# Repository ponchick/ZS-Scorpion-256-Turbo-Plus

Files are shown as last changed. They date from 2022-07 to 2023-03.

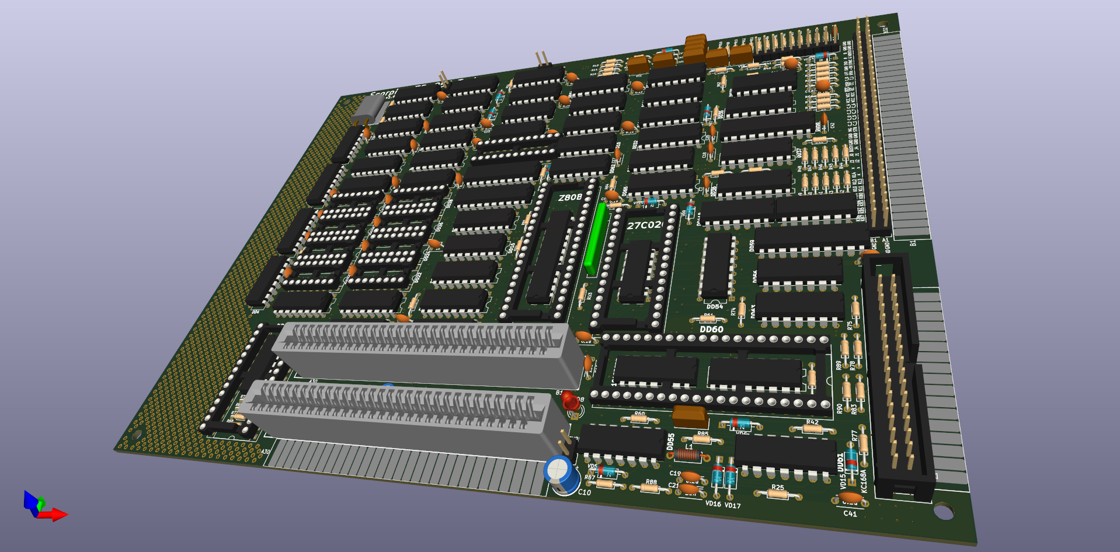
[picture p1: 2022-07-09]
Images/3D.png

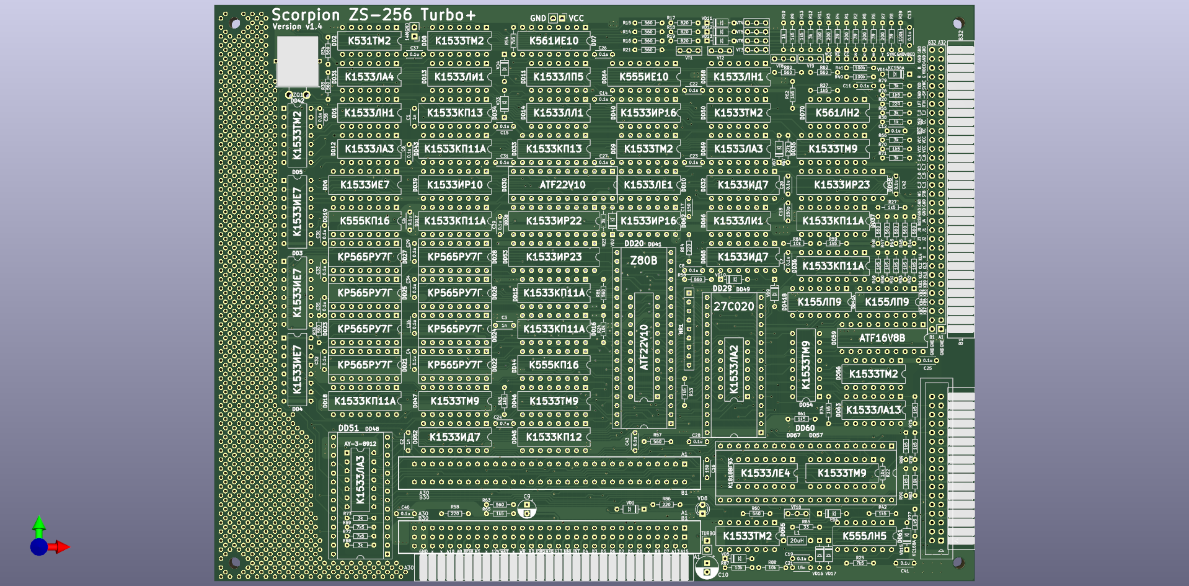
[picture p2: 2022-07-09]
Images/TOP.png

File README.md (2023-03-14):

# ZS-Scorpion-256-Turbo-Plus
Про плату хорошо написано в [этом репозитории](https://github.com/romychs/Scorpion256TPlus). Лучше я не напишу, а просто копировать не вижу смысла.

**Внимание! На данный момент произведена только первая пробная партия плат, в ней присутствуют ошибки. Если хотите отлаженую плату - заказывайте плату из репозотория выше.**
## Схема
[Схема](https://github.com/ponchick/ZS-Scorpion-256-Turbo-Plus/blob/main/gerber/Scorpion.pdf) в основном срисована со схемы @romychs версии 16.2.4. В основном отличия чисто косметические, но есть и более серьезные отличия:
- Добавлено больше деблокировочных конденсаторов.
- Возвращены краевые разъемы. В теории они должны нормально дружить как с разъемами с шагом 2,54 мм, так и с шагом 2,5 мм.
- Убрана макетка внизу платы в пользу более широких дорожек питания.
- Добавлена нормально-замкнутая перемычка на 6 ножку DD37. По умолчанию ножка притянута к земле, но можно перерезать перемычку и задействовать этот контакт для своих целей. К примеру, можно завести сигнал KEMPSTON-джойстика FIRE2.
- Добавлен необязательный планарный резистор R28. Он необходим только для [доработки выбора порта #7FFD по команде по команде "OUT(#FD),A"](https://github.com/ponchick/ZS-Scorpion-256-Turbo-Plus/blob/main/Images/7ffd.jpg)- в этом случае нужно перерезать дорожку между контактными площадками этого резистора и впаять сам резистор. Изначально доработка была сделана для ZXM-Phoenix, работает и для зелёного ZS Scorpion. Подробней можно почитать [тут](https://zx.clan.su/forum/8-66-808-16-1373062339).

## Печатная плата
Разводка изначально выполнялась по герберам пользователя molodcov_alex с форума [ZX-PK](http://zx-pk.ru) но из-за большого количества доработок полностью повторить плату не получилось. Основная цель была сделать так, все элементы были точно на своих местах, в случае невозможности - находиться как можно ближе к оригинальному расположению. Другие доработки:
- Из-за большого количества деблокировочных конденсаторов разводка некоторых дорожек сильно отличается от оригинала. 
- Посадочное место для плат расширения позволяет установить разъемы SL62.
- Часть элементов пришлось сдвинуть для удобства монтажа и для освобождения места для SL62. Это коснулось в основном только резисторов и конденсаторов, из МС сдвинута только DD48.
- Опять же для удобства монтажа унифицировано расстояние между ножками резисторов (7,62 мм) и конденсаторов (5,08 мм).
- Заметно увеличена площадь проводников VCC и GND.

## Найденые ошибки 
### Версия 1.4
- Ламели подходят только под шаг выводов 2.54, хотя изначально задумывались как универсальные под 2.5 и 2.54.
- Ошибка в описании резистора R28 на схеме.
- DD10 и DD30 слишком близко друг к другу.

## Файлы 
Герберы для производства можно найти в папке gerbers, [список деталей](https://htmlpreview.github.io/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) в папке [Interactive BOM](https://github.com/ponchick/ZS-Scorpion-256-Turbo-Plus/tree/main/Interactive%20BOM).

Все прошивки для ПЗУ и GAL есть в [репозитории варианта платы от @romychs](https://github.com/romychs/Scorpion256TPlus) и на [этой странице](https://speccy4ever.speccy.org/_SC.htm).

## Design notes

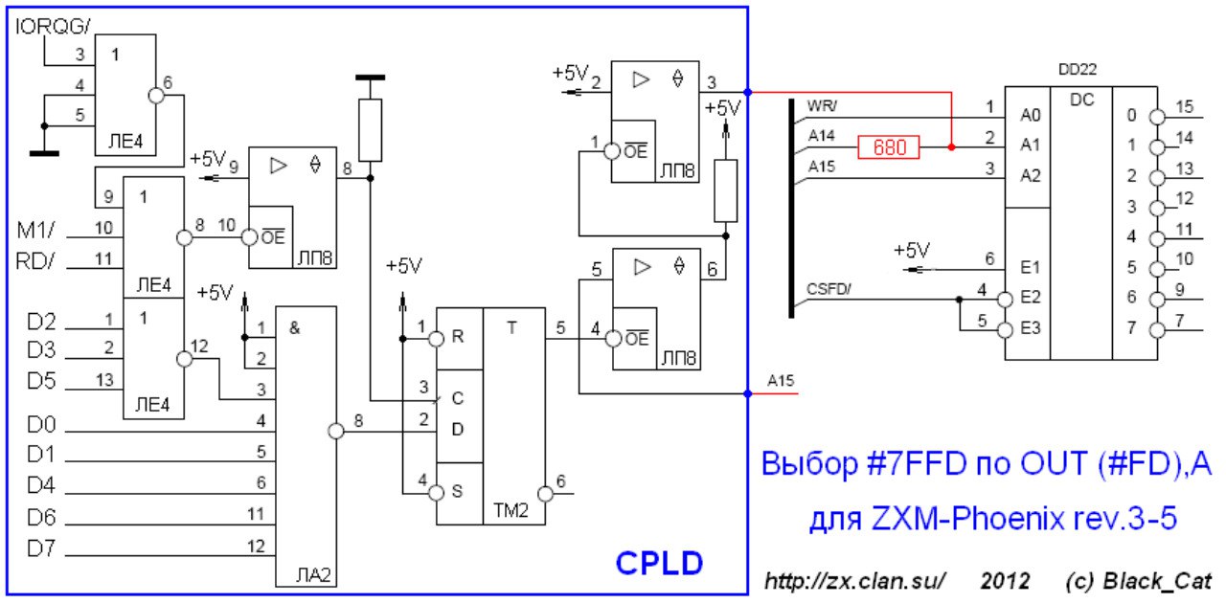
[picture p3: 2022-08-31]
Images/7ffd.jpg

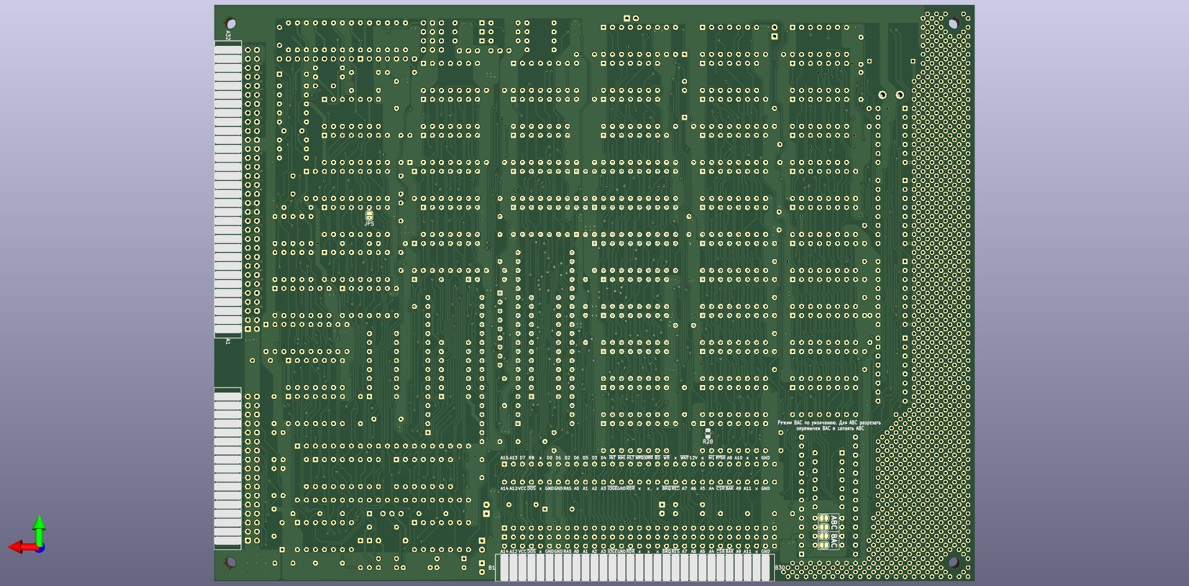
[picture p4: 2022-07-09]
Images/BOTTOM.png

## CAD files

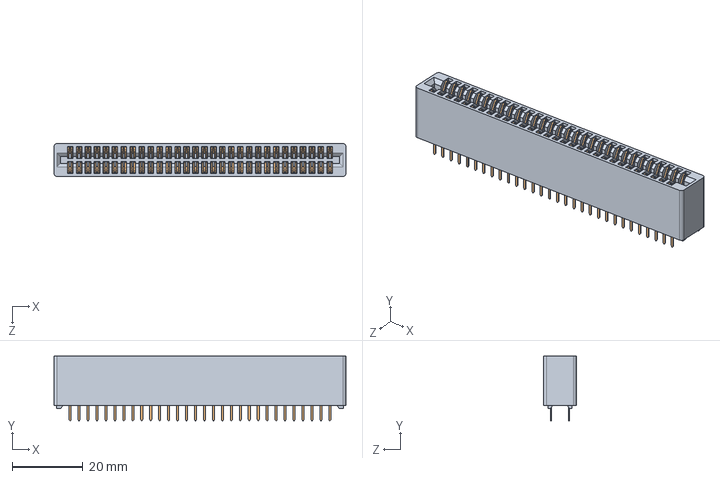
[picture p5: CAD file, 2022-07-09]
Scorpion/3D Models/edge_connector_60.STEP
82.8 x 18.3 x 9.30 mm
EDGE_CONN
EDGE_CONN_PIN x 60

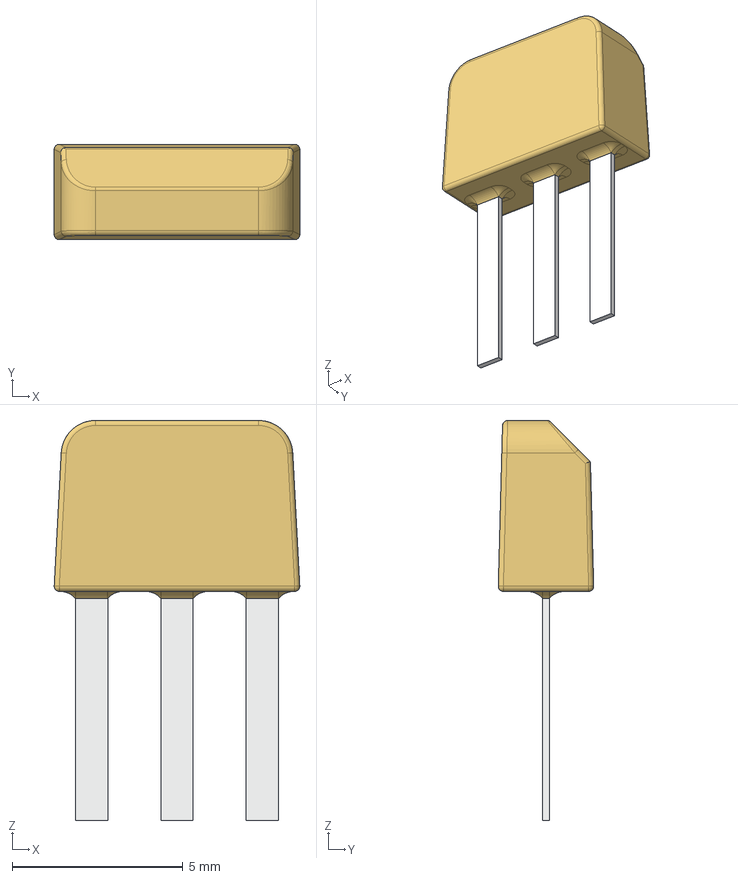
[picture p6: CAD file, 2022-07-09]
Scorpion/3D Models/KT-13-YEL.stp
7.18 x 2.79 x 11.7 mm

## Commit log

2022-07-09 Initial import
    [KT-13-YEL.stp, Scorpion.kicad_sch, edge_connector_60.STEP]
2022-07-09 BOM and gerber files added
2022-07-09 Renders and schematic added
    [Scorpion.kicad_sch]
2022-07-09 Readme modified
    [Scorpion.kicad_sch]
2022-08-31 Port 7FFD decryption fix described.
    [Scorpion.kicad_sch]
2022-09-15 Fixed minor silkscreen typos Sync Alternative and Value fields Remove unused user layers
    [Scorpion.kicad_sch]
2023-03-14 Fix R/Ro and G/Go signals
    [Scorpion.kicad_sch]
2023-03-14 Add footprint table to repo
